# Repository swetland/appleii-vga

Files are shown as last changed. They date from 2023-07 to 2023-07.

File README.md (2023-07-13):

# Apple II VGA PCB

This is a pair of PCBs that implements a version of the Apple II VGA design.

Please see the [Apple II VGA Project](https://github.com/markadev/AppleII-VGA) for details and firmware.

This version differs from the original in that:
1. It makes use of the Rpi Pico's regulator for 3v3 supply
2. It allows the SYNC signal to be optionally routed to the Rpi Pico (instead of allowing Apple II bus read operations)
3. It uses a fourth 74LVC245A instead of a 74LS07 for the remaining bus signals (fewer unique components)

The KiCAD source files are included in the [appleii.vga/](appleii.vga/)
and [appleii.vga.connector/](appleii.vga.connector/) directories.

The [export/](export/) directory contains gerber files suitable for fabrication.
Beware that only the v1.0.2 version has been fabricated so far (at JLCPCB).
The v1.1.0 version contains some minor improvements but has not yet been
fabricated and tested.

To use the standard firmware, install a 0 ohm resistor at R13 and leave R12 and R14 unpopulated.

PCBs and parts for assembly:

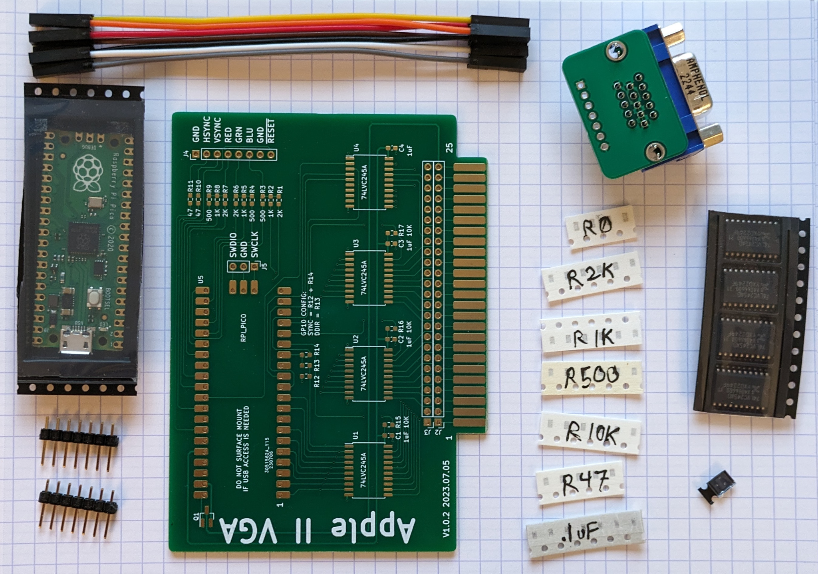
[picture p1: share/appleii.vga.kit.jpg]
pcb kit


Assembled PCBs:

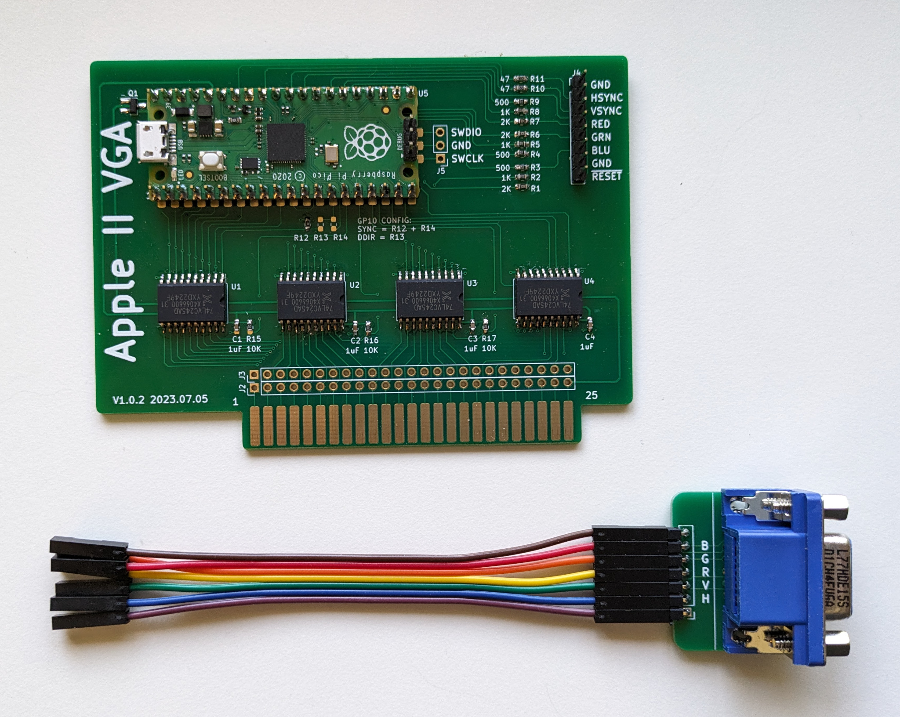
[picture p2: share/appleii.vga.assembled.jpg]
pcb assembled


Installed in an Apple IIe:

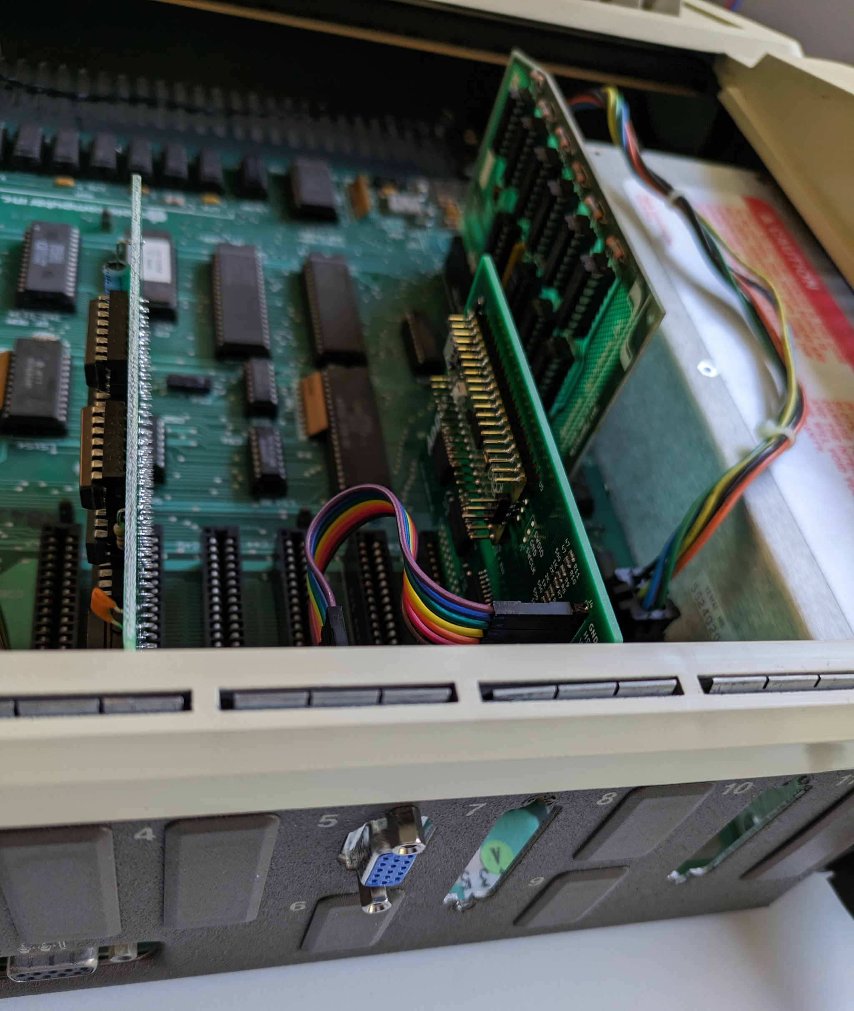
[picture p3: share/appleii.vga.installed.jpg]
pcb installed


Lode Runner displayed on a 15" Sony Trinitron VGA monitor:

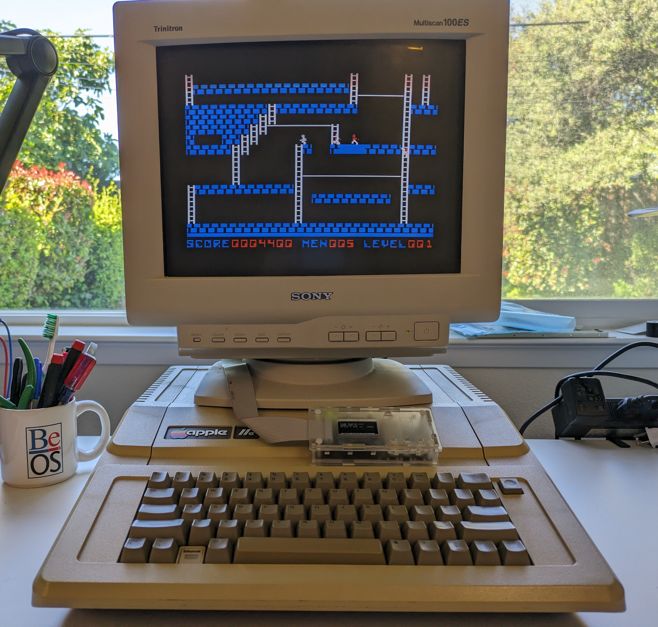
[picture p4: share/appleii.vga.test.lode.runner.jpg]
pcb tested


Schematic and Layout for v1.1.0:

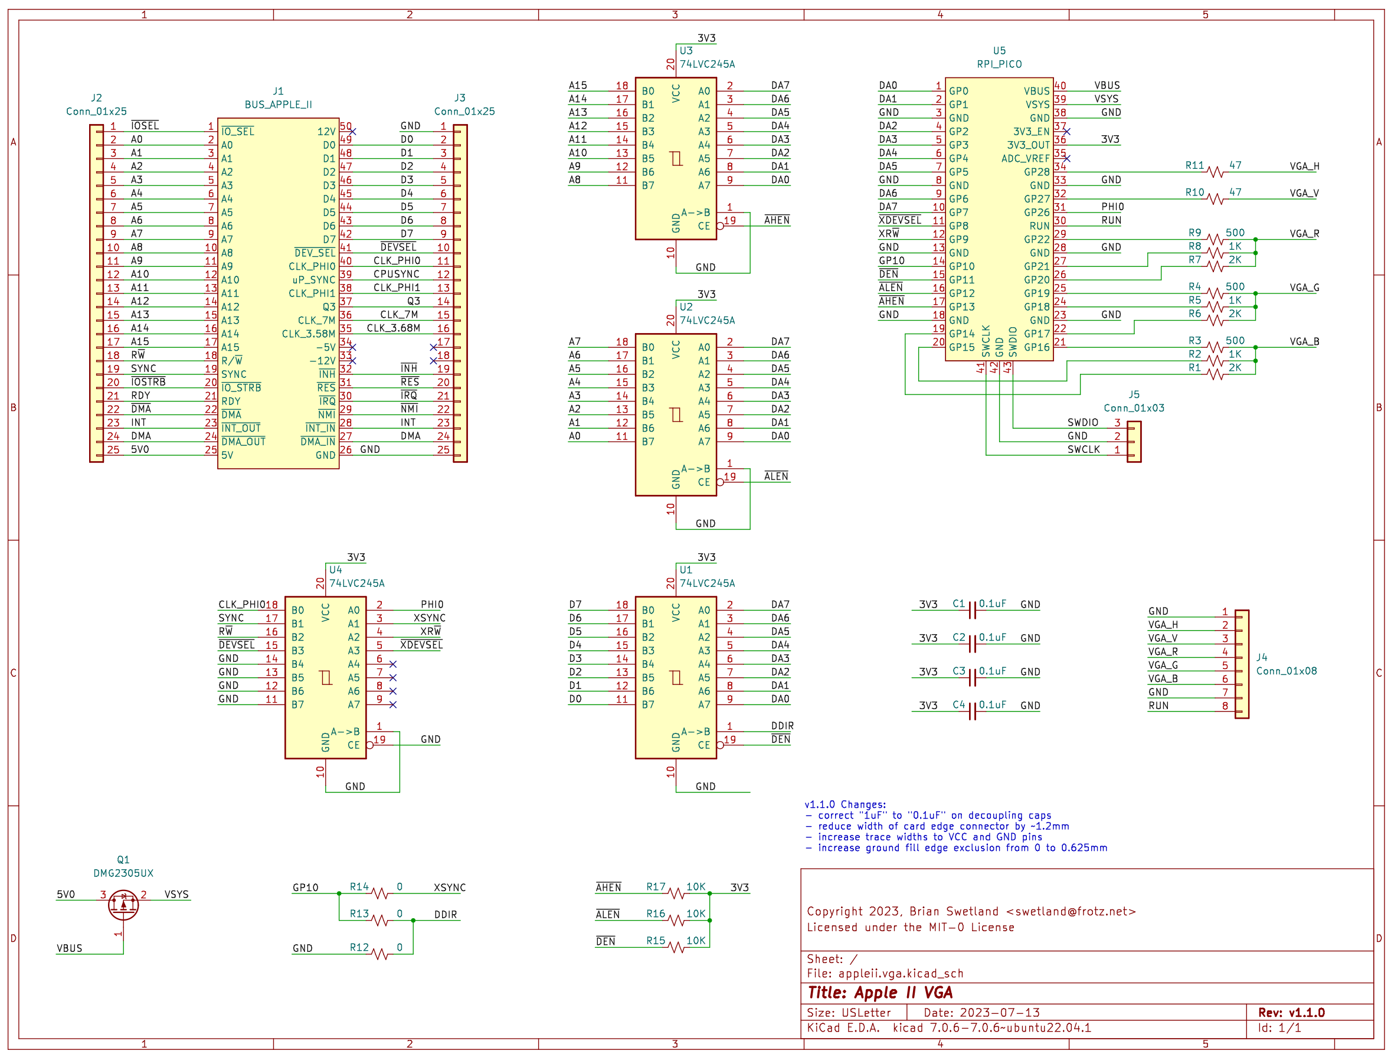
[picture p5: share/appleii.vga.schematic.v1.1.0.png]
schematic


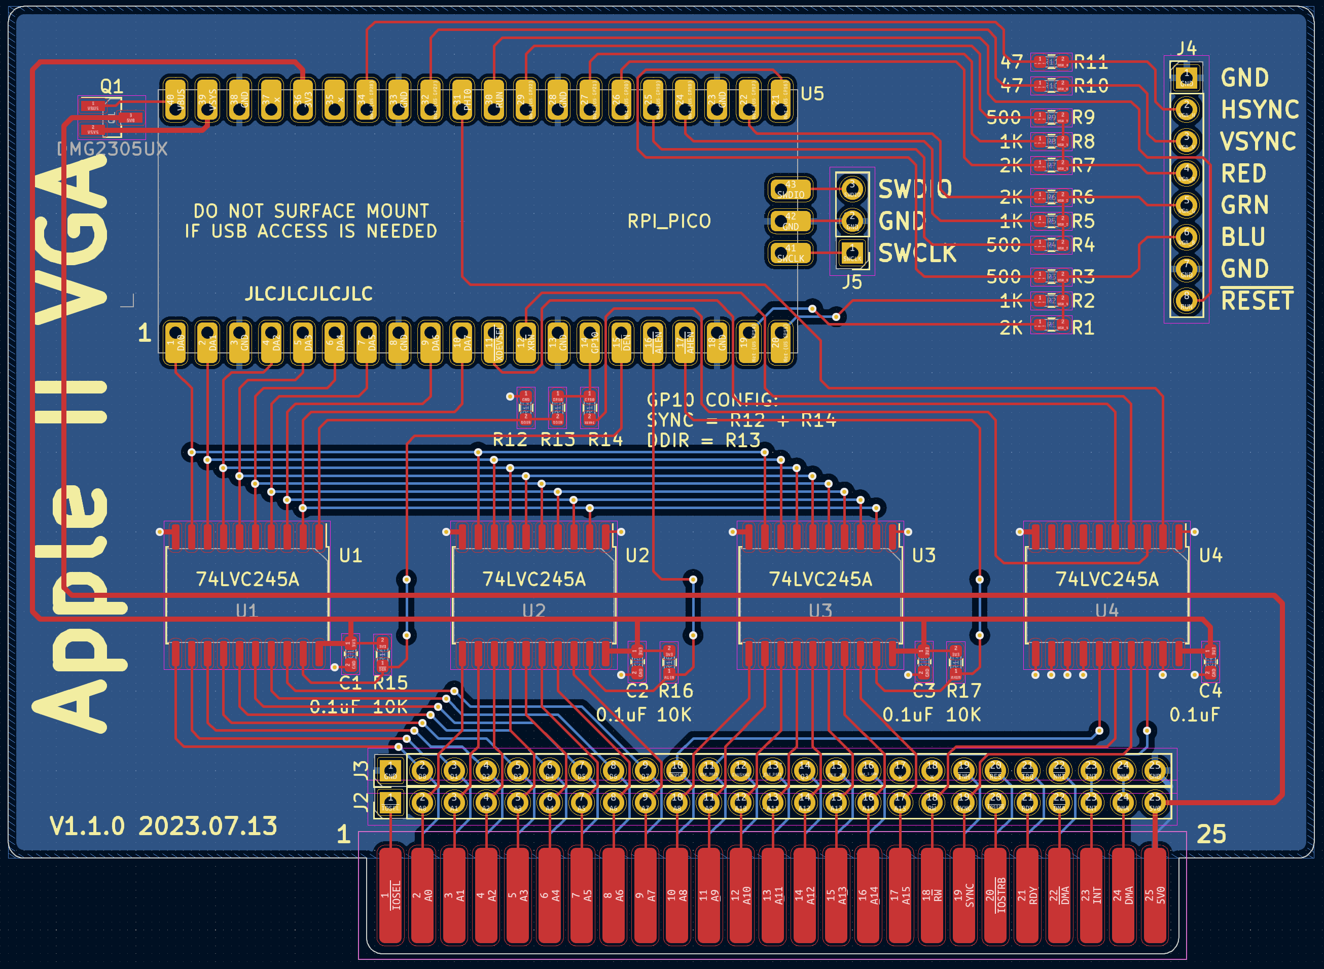
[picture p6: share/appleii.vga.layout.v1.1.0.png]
layout


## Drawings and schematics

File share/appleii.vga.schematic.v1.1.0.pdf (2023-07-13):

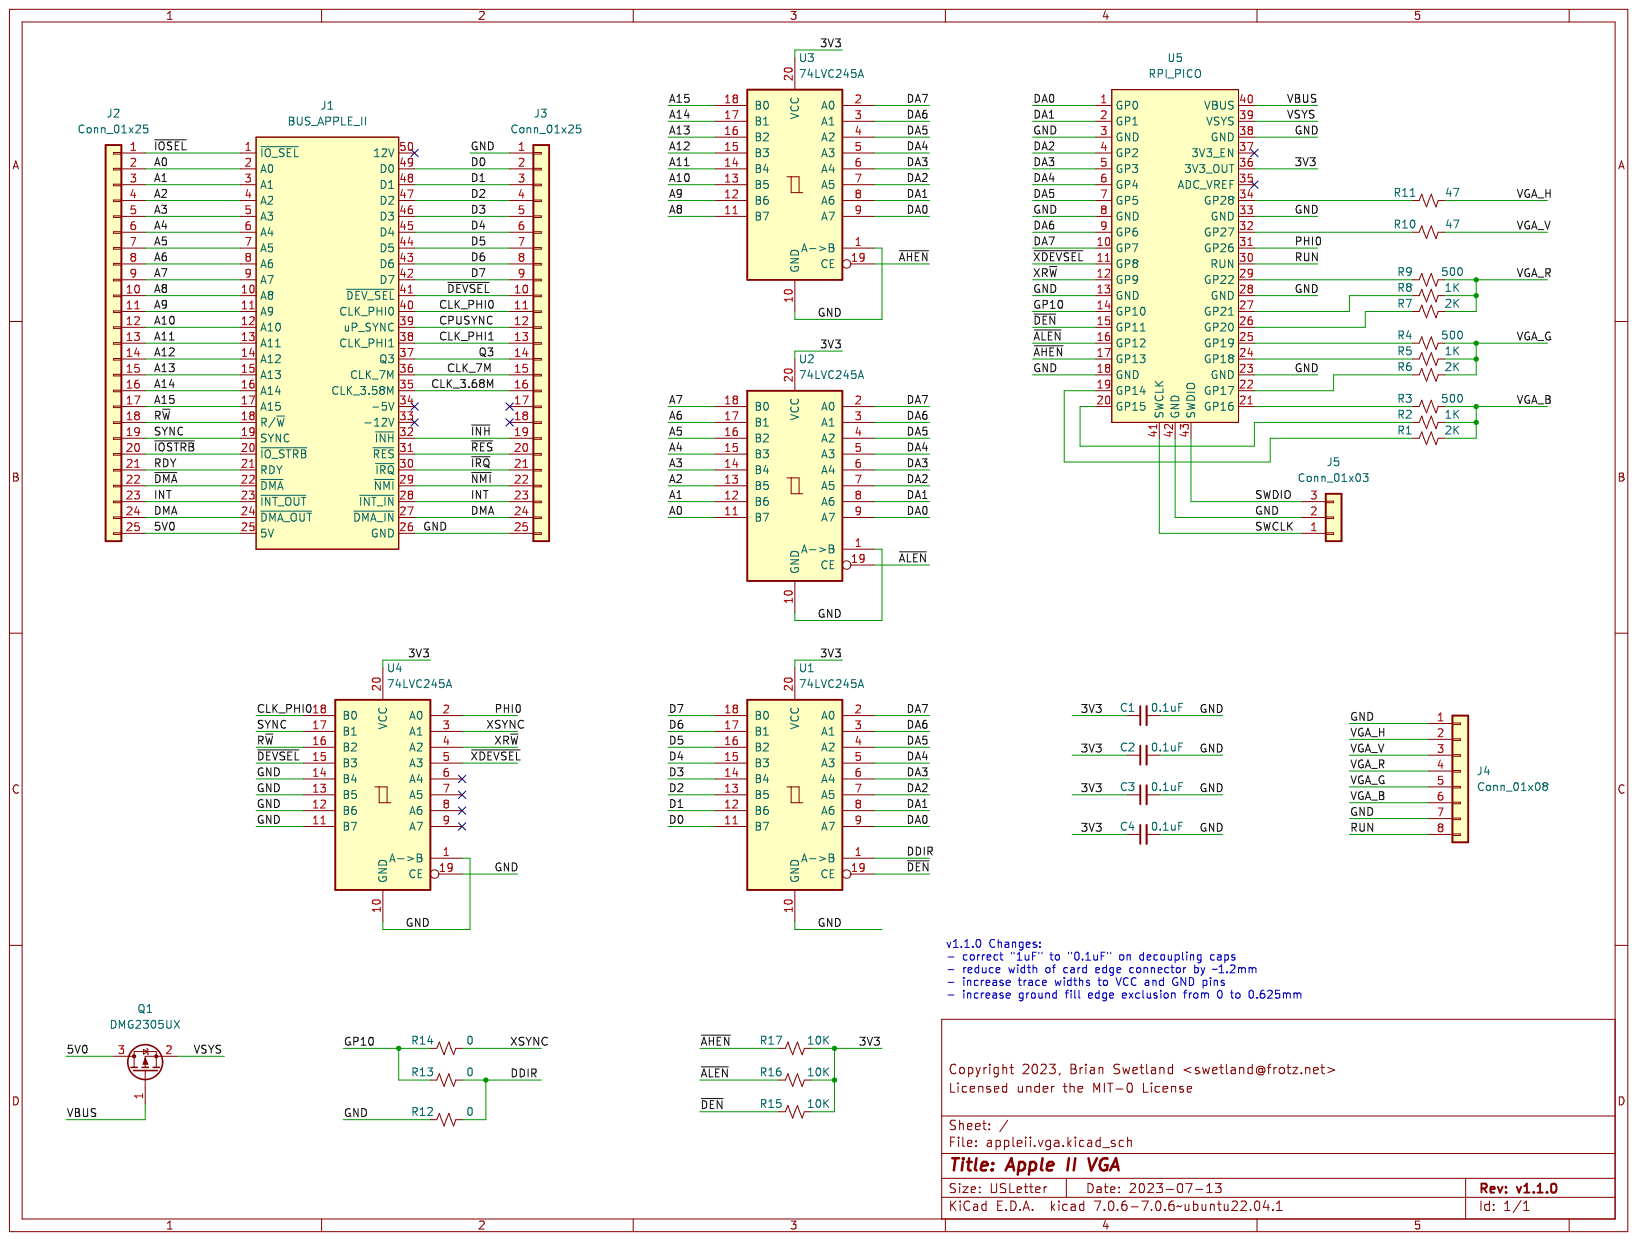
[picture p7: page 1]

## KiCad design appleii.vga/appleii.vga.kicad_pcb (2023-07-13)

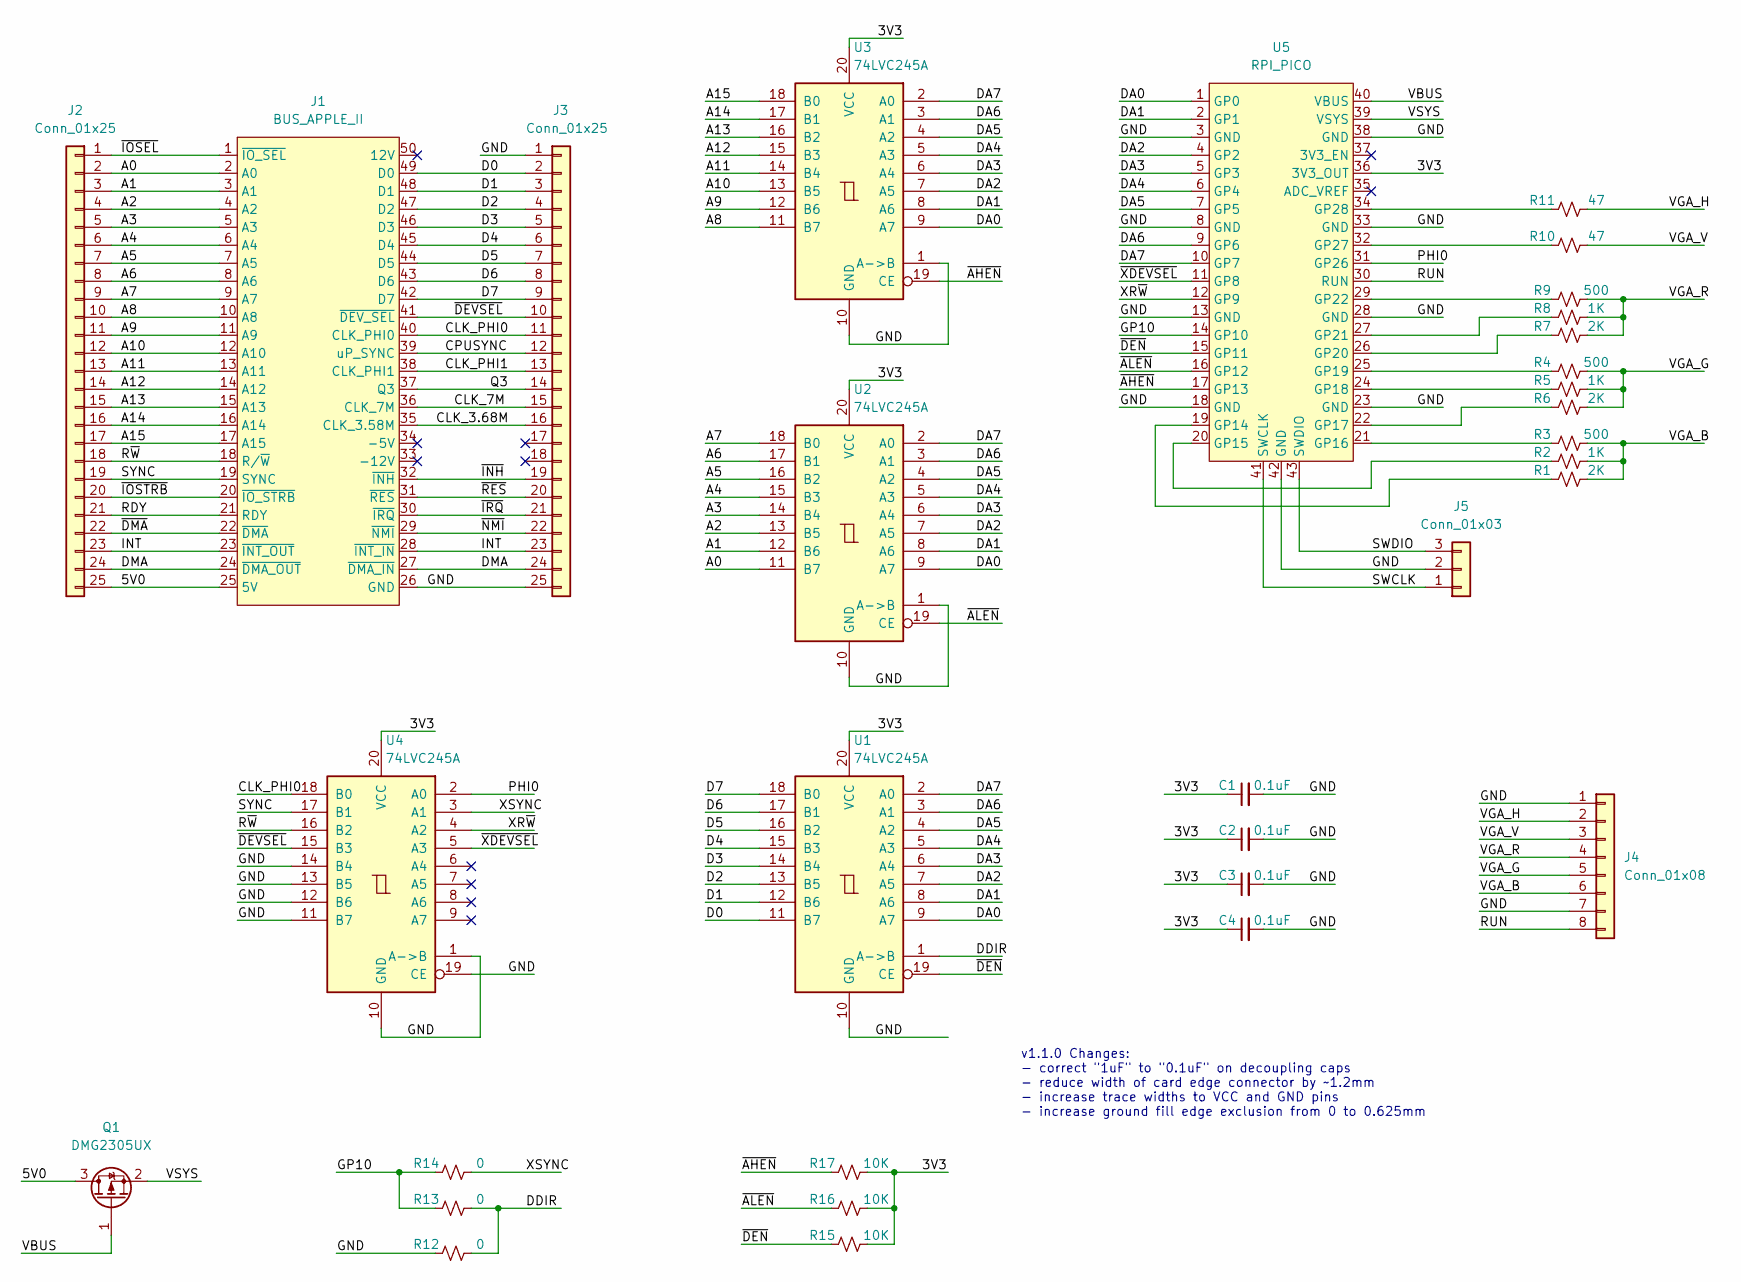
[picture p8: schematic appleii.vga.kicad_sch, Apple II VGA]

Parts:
C1, C2, C3, C4: 0.1uF; C_0603_1608Metric_Pad1.08x0.95mm_HandSolder
J1: BUS_APPLE_II
J2, J3: Conn_01x25; PinHeader_1x25_P2.54mm_Vertical
J4: Conn_01x08; PinHeader_1x08_P2.54mm_Vertical
J5: Conn_01x03; PinHeader_1x03_P2.54mm_Vertical
Q1: DMG2305UX; SOT-23_Handsoldering
R1, R6, R7: 2K; R_0603_1608Metric_Pad0.98x0.95mm_HandSolder
R2, R5, R8: 1K; R_0603_1608Metric_Pad0.98x0.95mm_HandSolder
R3, R4, R9: 500; R_0603_1608Metric_Pad0.98x0.95mm_HandSolder
R10, R11: 47; R_0603_1608Metric_Pad0.98x0.95mm_HandSolder
R12, R13, R14: 0; R_0603_1608Metric_Pad0.98x0.95mm_HandSolder
R15, R16, R17: 10K; R_0603_1608Metric_Pad0.98x0.95mm_HandSolder
U1, U2, U3, U4: 74LVC245A; SOIC-20W_7.5x12.8mm_P1.27mm
U5: RPI_PICO

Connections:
/3V3: C1.1, C2.1, C3.1, C4.1, R15.2, R16.2, R17.2, U1.20 (VCC), U2.20 (VCC), U3.20 (VCC), U4.20 (VCC), U5.36 (3V3_OUT)
/5V0: J1.25 (5V), J2.25, Q1.3 (D)
/A0: J1.2 (A0), J2.2, U2.11 (B7)
/A1: J1.3 (A1), J2.3, U2.12 (B6)
/A2: J1.4 (A2), J2.4, U2.13 (B5)
/A3: J1.5 (A3), J2.5, U2.14 (B4)
/A4: J1.6 (A4), J2.6, U2.15 (B3)
/A5: J1.7 (A5), J2.7, U2.16 (B2)
/A6: J1.8 (A6), J2.8, U2.17 (B1)
/A7: J1.9 (A7), J2.9, U2.18 (B0)
/A8: J1.10 (A8), J2.10, U3.11 (B7)
/A9: J1.11 (A9), J2.11, U3.12 (B6)
/A10: J1.12 (A10), J2.12, U3.13 (B5)
/A11: J1.13 (A11), J2.13, U3.14 (B4)
/A12: J1.14 (A12), J2.14, U3.15 (B3)
/A13: J1.15 (A13), J2.15, U3.16 (B2)
/A14: J1.16 (A14), J2.16, U3.17 (B1)
/A15: J1.17 (A15), J2.17, U3.18 (B0)
/CLK_3.68M: J1.35 (CLK_3.58M), J3.16
/CLK_7M: J1.36 (CLK_7M), J3.15
/CLK_PHI0: J1.40 (CLK_PHI0), J3.11, U4.18 (B0)
/CLK_PHI1: J1.38 (CLK_PHI1), J3.13
/CPUSYNC: J1.39 (uP_SYNC), J3.12
/D0: J1.49 (D0), J3.2, U1.11 (B7)
/D1: J1.48 (D1), J3.3, U1.12 (B6)
/D2: J1.47 (D2), J3.4, U1.13 (B5)
/D3: J1.46 (D3), J3.5, U1.14 (B4)
/D4: J1.45 (D4), J3.6, U1.15 (B3)
/D5: J1.44 (D5), J3.7, U1.16 (B2)
/D6: J1.43 (D6), J3.8, U1.17 (B1)
/D7: J1.42 (D7), J3.9, U1.18 (B0)
/DA0: U1.9 (A7), U2.9 (A7), U3.9 (A7), U5.1 (GP0)
/DA1: U1.8 (A6), U2.8 (A6), U3.8 (A6), U5.2 (GP1)
/DA2: U1.7 (A5), U2.7 (A5), U3.7 (A5), U5.4 (GP2)
/DA3: U1.6 (A4), U2.6 (A4), U3.6 (A4), U5.5 (GP3)
/DA4: U1.5 (A3), U2.5 (A3), U3.5 (A3), U5.6 (GP4)
/DA5: U1.4 (A2), U2.4 (A2), U3.4 (A2), U5.7 (GP5)
/DA6: U1.3 (A1), U2.3 (A1), U3.3 (A1), U5.9 (GP6)
/DA7: U1.2 (A0), U2.2 (A0), U3.2 (A0), U5.10 (GP7)
/DDIR: R12.2, R13.2, U1.1 (A->B)
/DMA: J1.24 (~DMA_OUT), J1.27 (~DMA_IN), J2.24, J3.24
/GND: C1.2, C2.2, C3.2, C4.2, J1.26 (GND), J3.1, J3.25, J4.1, J4.7, J5.2, R12.1, U1.10 (GND), U2.1 (A->B), U2.10 (GND), U3.1 (A->B), U3.10 (GND), U4.1 (A->B), U4.10 (GND), U4.11 (B7), U4.12 (B6), U4.13 (B5), U4.14 (B4), U4.19 (CE), U5.3 (GND), U5.8 (GND), U5.13 (GND), U5.18 (GND), U5.23 (GND), U5.28 (GND), U5.33 (GND), U5.38 (GND), U5.42 (GND)
/GP10: R13.1, R14.1, U5.14 (GP10)
/INT: J1.23 (~INT_OUT), J1.28 (~INT_IN), J2.23, J3.23
/PHI0: U4.2 (A0), U5.31 (GP26)
/Q3: J1.37 (Q3), J3.14
/RDY: J1.21 (RDY), J2.21
/RUN: J4.8, U5.30 (RUN)
/R~W: J1.18 (R/~W), J2.18, U4.16 (B2)
/SWCLK: J5.1, U5.41 (SWCLK)
/SWDIO: J5.3, U5.43 (SWDIO)
/SYNC: J1.19 (SYNC), J2.19, U4.17 (B1)
/VBUS: Q1.1 (G), U5.40 (VBUS)
/VGA_B: J4.6, R1.2, R2.2, R3.2
/VGA_G: J4.5, R4.2, R5.2, R6.2
/VGA_H: J4.2, R11.2
/VGA_R: J4.4, R7.2, R8.2, R9.2
/VGA_V: J4.3, R10.2
/VSYS: Q1.2 (S), U5.39 (VSYS)
/XR~W: U4.4 (A2), U5.12 (GP9)
/XSYNC: R14.2, U4.3 (A1)
/~AHEN: R17.1, U3.19 (CE), U5.17 (GP13)
/~ALEN: R16.1, U2.19 (CE), U5.16 (GP12)
/~DEN: R15.1, U1.19 (CE), U5.15 (GP11)
/~DEVSEL: J1.41 (~DEV_SEL), J3.10, U4.15 (B3)
/~DMA: J1.22 (~DMA), J2.22
/~INH: J1.32 (~INH), J3.19
/~IOSEL: J1.1 (~IO_SEL), J2.1
/~IOSTRB: J1.20 (~IO_STRB), J2.20
/~IRQ: J1.30 (~IRQ), J3.21
/~NMI: J1.29 (~NMI), J3.22
/~RES: J1.31 (~RES), J3.20
/~XDEVSEL: U4.5 (A3), U5.11 (GP8)
unnamed: R1.1, U5.19 (GP14)
unnamed: R2.1, U5.20 (GP15)
unnamed: R3.1, U5.21 (GP16)
unnamed: R6.1, U5.22 (GP17)
unnamed: R5.1, U5.24 (GP18)
unnamed: R4.1, U5.25 (GP19)
unnamed: R7.1, U5.26 (GP20)
unnamed: R8.1, U5.27 (GP21)
unnamed: R9.1, U5.29 (GP22)
unnamed: R10.1, U5.32 (GP27)
unnamed: R11.1, U5.34 (GP28)

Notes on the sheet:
v1.1.0 Changes: - correct "1uF" to "0.1uF" on decoupling caps - reduce width of card edge connector by ~1.2mm - increase trace widths to VCC and GND pins - increase ground fill edge exclusion from 0 to 0.625mm

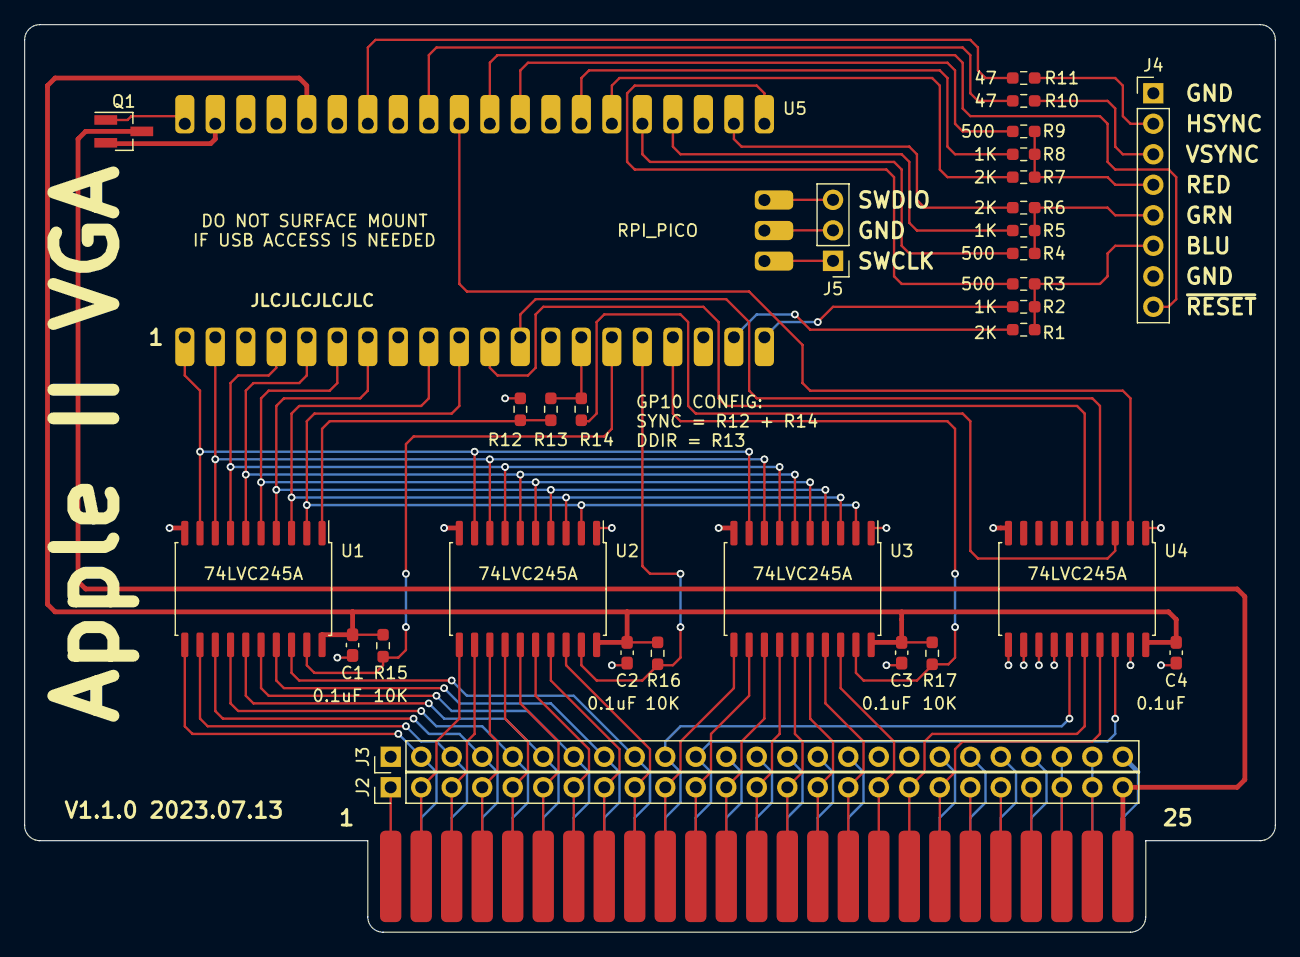
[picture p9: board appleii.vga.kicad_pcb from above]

Board: 2 copper layers, 104.1 x 75.6 mm, 32 parts (0 on the bottom side), 84 nets.

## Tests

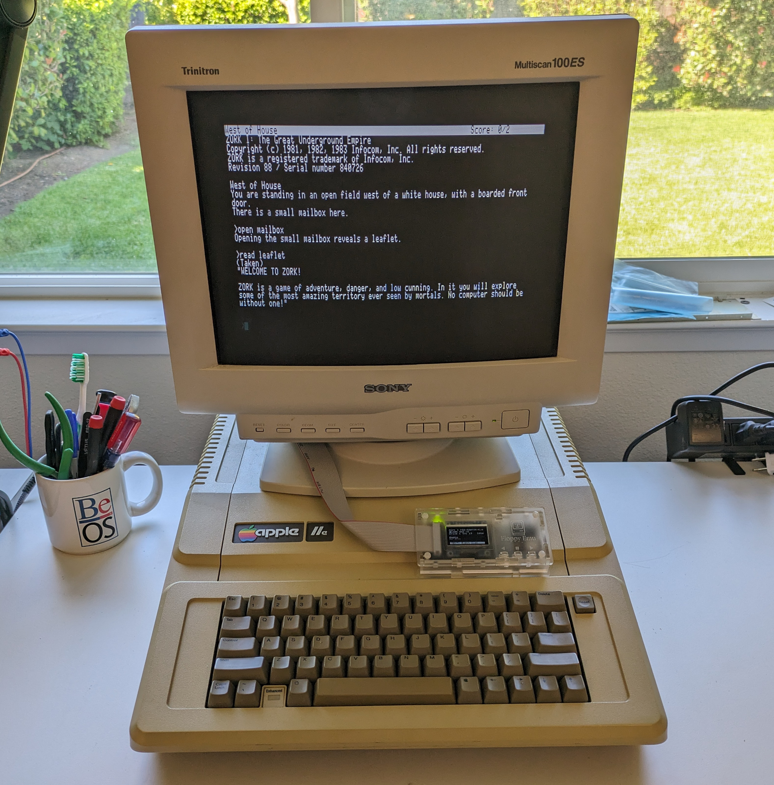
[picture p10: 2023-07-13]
share/appleii.vga.test.zork.i.jpg

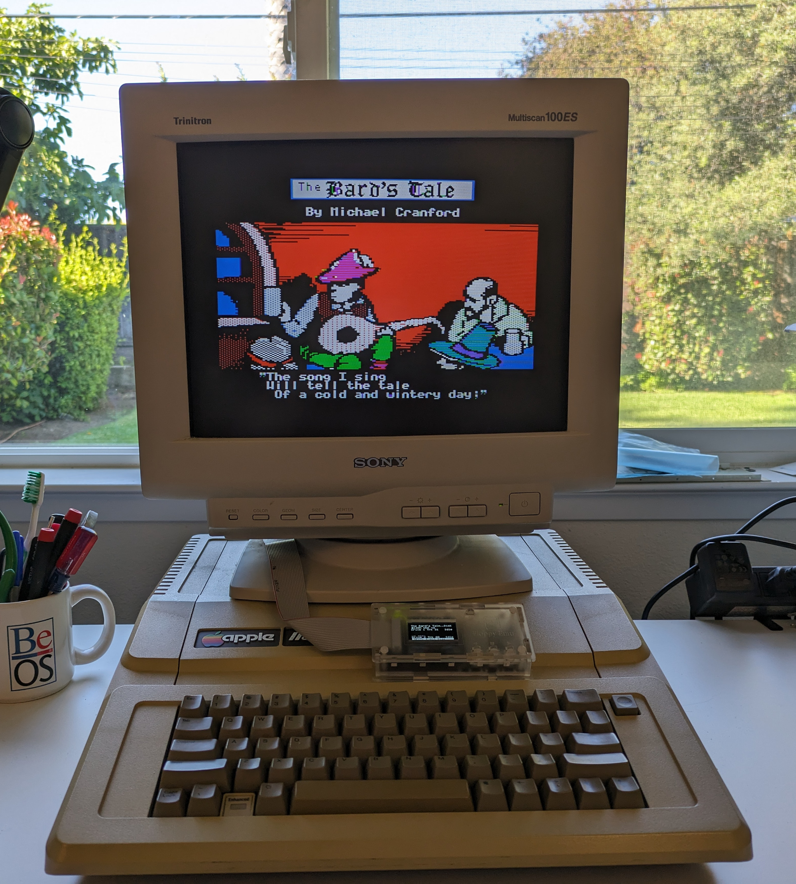
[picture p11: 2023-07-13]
share/appleii.vga.test.bards.tale.jpg

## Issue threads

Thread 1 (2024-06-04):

DMG2305UX

amazingcobrazil, 2024-06-04:
Hello, I'm not finding the DMG2305UX for sale easily. Is there any other direct equivalent with the same pinout? Could you use BSS84 for example?

swetland, 2024-06-05:
I selected the DMG2305UX based on the recommendation in section 4.5 of the
Pico datasheet:

"An example of a suitable P-MOSFET for most situations is Diodes DMG2305UX
which has a maximum Vt of 0.9V and
Ron of 100mΩ (at 2.5V Vgs)."

https://datasheets.raspberrypi.com/pico/pico-datasheet.pdf

On Tue, Jun 4, 2024 at 5:14 AM amazingcobrazil ***@***.***>
wrote:

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

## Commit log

2023-07-06 initial checkin - v1.0.2
    [appleii.vga.kicad_pcb, appleii.vga.kicad_sch]
2023-07-06 exported gerbers - v1.0.2
2023-07-06 change schematic page layout to us legal
    [appleii.vga.kicad_sch]
2023-07-13 upgrade to kicad 7
    [appleii.vga.kicad_pcb, appleii.vga.kicad_sch]
2023-07-13 update board to v1.1.0
    Some minor improvements based on v1.0.2 fab, assembly and test:
    - correct "1uF" to "0.1uF" on decoupling caps
    - reduce width of card edge connector by ~1.2mm
    - increase trace widths to VCC and GND pins
    - increase ground fill edge exclusion from 0 to 0.625mm
    [appleii.vga.kicad_pcb, appleii.vga.kicad_sch]
2023-07-13 move items into subdirectories
    [appleii.vga.kicad_pcb, appleii.vga.kicad_sch]
2023-07-13 add appleii.vga.connector schematic and layout
    [appleii.vga.connector.kicad_pcb, appleii.vga.connector.kicad_sch]
2023-07-13 update copyright in schematic
    [appleii.vga.kicad_sch]
2023-07-13 gerbers for v1.1.0
2023-07-13 fix copper fill edge clearance setting
    [appleii.vga.connector.kicad_pcb]
2023-07-13 add gerbers for connector board
2023-07-13 add pdf and png versions of schematic and layout
